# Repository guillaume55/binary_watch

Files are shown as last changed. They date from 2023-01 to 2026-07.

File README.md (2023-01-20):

# Binary watch

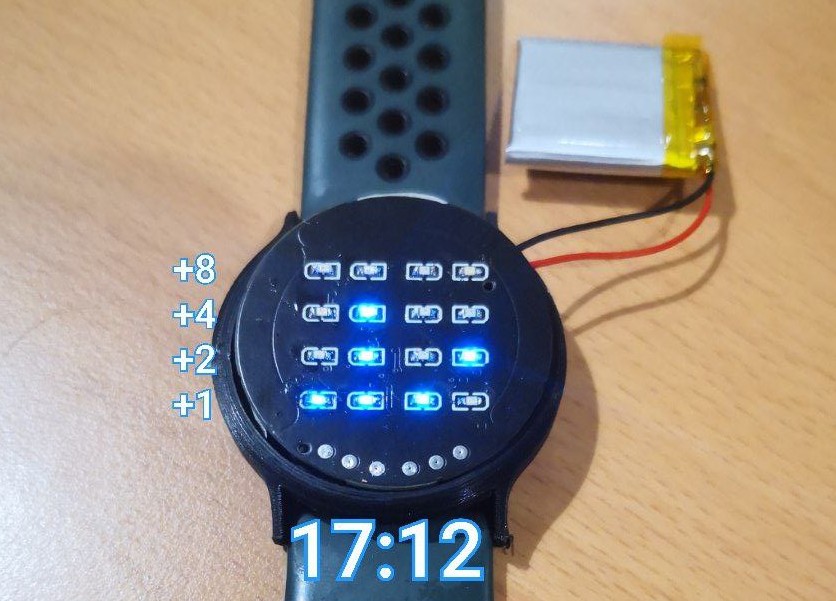
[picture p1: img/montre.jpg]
Binary watch


## How to read time
How to read it (BCD, binary coded digits)
Each digit is separated. The two first digits are for the hours, the two last for minutes
the Bottom digit adds 1, the second 2, the third 4, and the top one 8
For instance if # are on and _ are off

```
//First screen, time (24h format)
_ _ _ _
_ _ # #
_ # _ #
# # _ #

1 3:4 7

//second screen, date (DD/MM)
_ _ _ _
_ _ _ _
_ # _ #
# _ _ #

1 2:0 3 (March 12th)

//third screen, stop watch (indicated led will be on for one second (3rd led, 3rd screen) and the stopwatch will begin counting)
_ _ # _
_ _ _ _
_ _ _ _
_ _ _ _

1 3:4 7

//last screen, Full battery level here
_ _ _ #
_ _ _ #
_ _ _ #
_ _ _ #
```

## Features
* Read time and date (24h format, DD/MM)
* Set time and date
* Use stopwatch
* Battery level

## Four different screens
Navigate between screens with right button
Return to first screen with top button
* Display time (24h format)
* Display date (DD/MM)
* Stopwatch
* See battery level (will return to first screen after few seconds)

## How to use it

### Powered on, screen off (Idle)
Use top button to unlock (wake up from sleep) the watch. It will go to sleep after ON_DURATION (default 10s)
It can be a bit long for the watch to show something as the default pooling interval is 3s.

### Main screen with menus
* Right button: Set time (and date)
* Top button: Return to time display (menu index 0, useful if you are lost)
* Left button: Change mode, Time(1), Date(2), Stopwatch(3), Remaining battery(4) in this order. Lower led will be on for one second to indicate the index before displaying the mode

### Set time and date
An animation will tell you that you have clicked on setTime
* Right button: go to next digit to modify. Hours are modified at the same time, minutes are digit by digit)
* Top button: no action
* Left button: increase the time or date

A second animation (faster) will tell you that you now have to set the date (DD/MM). When done, press left. Last animation, and main screen will appear. Year should be written manually

### Stopwatch
* Right button: Next menu (will be battery level)
* Top button: No action
* Left button: Pause/Resume

### Battery level
Show battery level as a vertical bar on last column
```
//Full battery  --> low battery
_ _ _ #             _ _ _ _
_ _ _ #             _ _ _ _
_ _ _ #             _ _ _ _
_ _ _ #             _ _ _ #

```

## Power consumption
* 0.44mA in sleep (standby) mode. Wake up sometimes to poll user touch on button (Would need more tools to see average consumption)

## BOM
* SWD programmer (I use Seeedstudio XIAO as DAPLINK, see https://wiki.seeedstudio.com/Seeeduino-XIAO-DAPLink/)
* PCB, files in PCB/ are JLCPCB ready
* 3D printed or machined case
* 22mm watch strap
* At least 3 crocodile pliers
* 302323 battery (110mAh)
* Wireless charger

## Getting started with XIAO as DAPLINK and Arduino IDE
First, connect the programmer. For XIAO, connect
* XIAO GND to GND
* XIAO VCC to watch Vin on the microcontroller side
* XIAO 9 to Watch SWDIO
* XIAO 10 to Watch SWDCLK

Install libraries
* Adafruit freetouch (from arduino library manager)
* RTCZero (from arduino library manager)

Now burn bootloader and program it
* Start XIAO in bootloader mode (connect usb and restart it twice (see SeeedStudio page)
* Select Arduino Zero (programming port) board and XIAO port (Don't select XIAO BOARD!)
* Burn Bootloader
* Flash board (CRTL + U)

## Print case
Current version should be printed, next will be machinable
Use small layer heights

## PCB
You can provide directly file to JLCPCB
I have chosen one side assembly (microcontroler side) to reduce cost
I hand soldered leds, it can be cleaner but it's a fair job. You can train on another PCB because leds are very small. You should use a good quality precision iron, a standard size will make the job too hard and the looks terrible

## Known issue
After programming, the watch sleeps at 7.28mA. No idea why, but the problem disappear after restart

## Possible improvements
* Don't use arduino framework, there is room to improve consumption by reducing clock speed for example
* Use a more precise oscillator (as the precision is very low) or use the internal oscillator only
* Reset button or pad, maybe replace front 2.8V pad by reset pad
* Use another microcontroller optimized for low power, for example SAML21 (not in stock and available for assembly) or a STM32
* Improve hardware consumption

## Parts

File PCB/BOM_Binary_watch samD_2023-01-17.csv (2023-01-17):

ID | Name | Designator | Footprint | Quantity | Manufacturer Part | Manufacturer | Supplier | Supplier Part | Price
1 | 1uF | C1,C2,C24 | C0402 | 3 | CL05A105KA5NQNC | SAMSUNG | LCSC | C52923 | 0.001
2 | 10uF | C14,C21,C22 | C0402 | 3 | CL05A106MQ5NUNC | SAMSUNG | LCSC | C15525 | 0.001
3 | 100nF | C23,C28,C29 | C0402_NEW | 3 | CL05B104KO5NNNC | SAMSUNG(三星) | LCSC | C1525
4 | 10pF | C26,C27 | C0402 | 2 | CL05C100JB5NNNC | SAMSUNG(三星) | LCSC | C32949 | 0.001
5 | HDR-F-2.54_1x2 | H1,H2 | PADS_FOR_BATTERY | 2 |  |  | LCSC | C49661 | 0.006
6 | 19-217/GHC-YR1S2/3T | LED1EMERALD | LED0603-R-RD | 1 | 19-217/GHC-YR1S2/3T | EVERLIGHT(亿光) | LCSC | C72043 | 0.004
7 | 19-213/Y2C-CQ2R2L/3T(CY) | LED1YELLOW | LED0603-R-RD | 1 | 19-213/Y2C-CQ2R2L/3T(CY) | EVERLIGHT(亿光) | LCSC | C72038 | 0.004
8 | 19-217/BHC-ZL1M2RY/3T | LED2BLUE,LED3BLUE,LED4BLUE,LED5BLUE,LED6BLUE,LED7BLUE,LED8BLUE,LED9BLUE,LED10BLUE,LED11BLUE,LED12BLUE,LED13BLUE,LED14BLUE,LED15BLUE | LED0603-R-RD_BLUE | 14 | 19-217/BHC-ZL1M2RY/3T | EVERLIGHT(亿光) | LCSC | C72041 | 0.003
9 | CONN-TH_3P-P5.00 | P1 | QTOUCH-BUTTONS | 1 |  |  | LCSC
10 | 100K | R1,R2 | R0402 | 2 | 0402WGF1003TCE | UniOhm | LCSC | C25741
11 | 10K | R3,R4 | R0402 | 2 | 0402WGF1002TCE | UniOhm | LCSC | C25744
12 | 1K | RN1,RN2,RN4,RN5 | RES-ARRAY-SMD_0603-8P-L3.2-W1.6-BL | 4 | 4D03WGJ0102T5E | UniOhm | LCSC | C20197 | 0.001
13 | MCP73831T-2ACI/OT | U2 | SOT-23-5_L3.0-W1.7-P0.95-LS2.8-BR | 1 | MCP73831T-2ACI/OT | Microchip Tech | LCSC | C424093 | 0.128
14 | ATSAMD21G18A-AU | U3 | TQFP-48_L7.0-W7.0-P0.50-LS9.0-BL | 1 | ATSAMD21G18A-AU | MICROCHIP(美国微芯) | LCSC | C78624 | 0.722
15 | AMS1117-5.0_C2718490 | U5 | SOT-89-3_L4.5-W2.5-P1.50-LS4.2-BR | 1 | AMS1117-5.0 | JSMSEMI(杰盛微) | LCSC | C2718490 | 0.017
16 | MD57E28QC3 | U6 | SOT-23-5_L2.9-W1.6-P0.95-LS2.8-BL | 1 | MD57E28QC3 | 明达微 | LCSC | C920560 | 0.021
17 | pad | U8,U11,U12,U14,U15,U16 | PAD | 6
18 | 32.768kHz | X3 | OSC-SMD_L3.2-W1.5 | 1 | Q13FC1350000300 | EPSON(爱普生) | LCSC | C99010 | 0.043

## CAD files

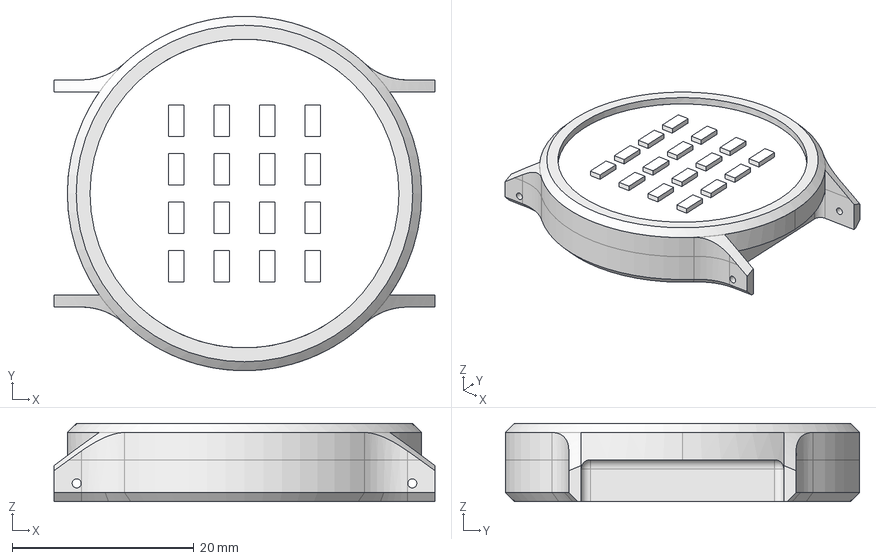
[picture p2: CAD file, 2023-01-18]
CAD/montre.FCStd
41.9 x 39.0 x 8.60 mm
PCB
battery
wireless receiver
watch 3
led

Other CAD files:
CAD/montre.stl

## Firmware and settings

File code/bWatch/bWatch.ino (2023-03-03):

/*******************************
 * Binary watch version 0.1
 *
 * How to read it (BCD, binary coded digits)
 * Each digit is separated. The two first digits are for the hours, the two last for minutes
 * the Bottom digit adds 1, the second 2, the third 4, and the top one 8
 * For instance if # are on and _ are off
 *      _ _ _ _           ex 2)   _ _ _ _
 *      _ _ # #                   _ _ _ #
 *      _ # _ #                   # _ # _
 *      # # _ #                   _ # # #
 *      1 3:4 7                   2 1:3 5
 *
 * Buttons
 * Top button, Unlock and show time
 * Left button : set time and then date
 * Right button : change mode (time, date, stopwatch, remaining battery)
 * See readme for more details
 * Power consumption depend a lot on selected board. Arduino zero consumes 0.44mA during standby, sparkfun SAMD21 Dev only 0.27mA
 *
 *******************************/

 //Arduino_MCHPTouch.h ?

#include <RTCZero.h>
#include <time.h>
#include "Adafruit_FreeTouch.h"
#include "ArduinoLowPower.h"

#define BUTTON_RIGHT 42//PA03
#define BUTTON_LEFT A5//PB02
#define BUTTON_TOP A1//PB08
#define BATTERY_PROBE 25 //PB03;

#define QTOUCH_THRESHOLD 500

#define ON_DURATION 10000 //sec during which the watch is showing time
#define SLEEP_DURATION 3 //sec during which the device is sleeping. Correspond to the max amount of time between 2 readings of the capacitive button

Adafruit_FreeTouch qt_top = Adafruit_FreeTouch(BUTTON_TOP, OVERSAMPLE_4, RESISTOR_50K, FREQ_MODE_NONE);
Adafruit_FreeTouch qt_left = Adafruit_FreeTouch(BUTTON_LEFT, OVERSAMPLE_4, RESISTOR_50K, FREQ_MODE_NONE);
Adafruit_FreeTouch qt_right = Adafruit_FreeTouch(BUTTON_RIGHT, OVERSAMPLE_4, RESISTOR_50K, FREQ_MODE_NONE);

RTCZero rtc;

//Pins for Arduino Zero (Programming port) board. Do not forget to burn the bootloader
const int ledPin [4][4] = { {0,0,17,16}, //1st digit of hours, The two first leds are not connected to the uC
                          {9,8,18,14}, //2nd digit of hours
                          {24,23,7,6}, //1st digit of min
                          {22,38,20,21}  //2nd digit of min
                        };

int ledState [4][4] = { {0,0,0,0}, //1st digit of hours
                        {0,0,0,0}, //2nd digit of hours
                        {0,0,0,0}, //1st digit of min
                        {0,0,0,1}  //2nd digit of min, shows one led to say that everything is working
                      };

unsigned long pm = 0;
uint8_t menuIndex = 0; //(dispaly time, date, stopwatch, remaining battery)
bool wasSleeping = false;

void setup() {
  //set leds as ouputs
  for(int i=0; i<4; i++)
  {
    for(int j=0; j<4; j++)
    {
      pinMode(ledPin[i][j], OUTPUT);
      digitalWrite(ledPin[i][j], ledState[i][j]);
    }
  }

  ledsTest(3); // set a delay to ease programming, sleep mode can interfere with prog mode
  //not actually needed if we use a programmer

  // Setup the RTC
  rtc.begin(false); //don't reset time

  //disable usb 
  USBDevice.detach();

//most of the power consumption is here. make the standby current goes from 0.08mA to 0.27mA
  if (! qt_top.begin() || ! qt_left.begin() || ! qt_right.begin() )  //eror with qtouch makes col 2 blink
  {
    digitalWrite(21,!digitalRead(21));
    delay(500);
  }
  saveTime(12, 11); //the watch is not supposed to shudown. Display at least something when it boots
}

void loop() {

  if(qt_top.measure() > QTOUCH_THRESHOLD)  //unlock and display the time
  {
    wasSleeping = false;
    timeToLeds();
    delay(3000);
    pm = millis();
    menuIndex = 0; //return to first screen (time) if you are lost
  }

  if(qt_right.measure() > QTOUCH_THRESHOLD /*&& wasSleeping = false*/)
  {
    wasSleeping = false;
    menuIndex = (menuIndex+1) % 4;
    //show index for 1s
    digitalWrite(ledPin[menuIndex][0], HIGH);
    delay(500);
    digitalWrite(ledPin[menuIndex][0], LOW);

    if(menuIndex == 0)
      timeToLeds();
    if(menuIndex == 1)
      dateToLeds();
    if(menuIndex == 2){
      stopwatch();
      menuIndex++; //don't forget to inc menu because stopwatch is a new screen
    }
    if(menuIndex == 3){
      remainingBattery(3000);
    }
    pm = millis();
  }

  if(qt_left.measure() > QTOUCH_THRESHOLD /*&& wasSleeping = false*/)
  {
    wasSleeping = false;
    ledsTest(0.75);
    setTime();
    ledsTest(0.5); //faster animation
    setDate();
    ledsTest(0.5);

    menuIndex = 0; //return to time display
    pm = millis();
  }

  //sleeps after timeout or if we woke up and the user didn't touch any button
  if(millis() - pm > ON_DURATION || wasSleeping == true){
    // Sleep until the next interrupt
    ledsOff();
    wasSleeping = true;
    LowPower.sleep(3000);
  }
  delay(100);
}

//show the leds that are supposed to be on
void ledsShow()
{
  ledsOff();
  for(int i=0; i<4; i++)
  {
    for(int j=0; j<4; j++)
    {
      digitalWrite(ledPin[i][j], ledState[i][j]);
    }
  }
}

//shut off all leds
void ledsOff()
{
  for(int i=0; i<4; i++)
  {
    for(int j=0; j<4; j++)
    {
      digitalWrite(ledPin[i][j], 0);
    }
  }
}

void ledsColOff(int col)
{
    for(int j=0; j<4; j++)
    {
      digitalWrite(ledPin[col][j], 0);
    }
}

void ledsTest(float speed)
{
  for(int i=0; i<4; i++)
  {
    for(int j=0; j<4; j++)
    {
      digitalWrite(ledPin[i][j], 1);
      delay(100*speed);
      digitalWrite(ledPin[i][j], 0);
      delay(50*speed);
    }
  }
}

void remainingBattery(int time)
{
  ledsOff();
  int voltage = analogRead(BATTERY_PROBE);
  //voltage dividor cuts volts of the battery in half
  //Supply voltage is 2.8V

  //voltage = ( 2.8 * 1023 ) / voltage;
  if(voltage > 2200)
    digitToLedColumn(0b1111, 3);
  else if(voltage > 1600)
    digitToLedColumn(0b0111, 3);
  else if(voltage > 1100)
    digitToLedColumn(0b0011, 3);
  else {
    digitToLedColumn(0b0001, 3);
  }
  ledsShow();
  delay(time);  //stay a bit on this screen
  digitToLedColumn(0b0000,4); //remove on "buffer"
  ledsOff(); //shutdown leds
}

void timeToLeds()
{
  ledsOff();
  // Get time as an epoch value and convert to tm struct
  time_t epoch = rtc.getEpoch(); //we can use directly getHours and getMinutes but I'm coming from RtcCounter lib
  struct tm* t = gmtime(&epoch);

  int timeArr[4] = { ( (t->tm_hour/10) % 10 ),  //1st digit of hours
                     ( (t->tm_hour) % 10 ),  //2nd of hours
                     ( (t->tm_min/10) % 10 ),  //1st digit of min
                     ( (t->tm_min) % 10 )   //2nd of min
                    };

  for(int i=0; i<4; i++)  //read and copy the bits from digit to led digit
  {
    digitToLedColumn(timeArr[i],i);
  }
  ledsShow();
}

void dateToLeds() //close to TimeToLeds
{
  ledsOff();
  // Get time as an epoch value and convert to tm struct
  //time_t epoch = rtcCounter.getEpoch();
  time_t epoch = rtc.getEpoch();
  struct tm* t = gmtime(&epoch);

  //do +1 because RTC starts at 0 and human month and days at 1
  int timeArr[4] = {(t->tm_mday+1) / 10,  //1st digit of month day
                    (t->tm_mday+1) % 10,  //2nd of month day
                    (t->tm_mon + 1) / 10,  //1st digit of month
                    (t->tm_mon + 1) % 10  //2nd of month
                  };

  for(int i=0; i<4; i++)  //read and copy the bits from digit to led digit
  {
    digitToLedColumn(timeArr[i], i);
  }
  ledsShow();
}

void digitToLedColumn(uint8_t digit, int column)
{
  for(int i=0; i<4; i++)  //read and copy the bits from digit to led digit
  {
    ledState[column][3-i] = bitRead(digit, i); //starting from the rightmost bit and copying it to the bottom led
  }
}

void setTime()
{
  int index = 0;
  uint8_t hour = rtc.getHours();
  uint8_t minute = 11; //the two bottom leds will be on

  //display current value
  hour = hour-1; //if init will do +1, counter it
  bool doInit = 1; //force display

  //top button to quit if not finished, better to click right
  while(qt_top.measure() < QTOUCH_THRESHOLD+100 && index < 4)
  {
    //hours modified, edit sec
    if(qt_right.measure() > QTOUCH_THRESHOLD){
      if(index == 0){
        index += 2; //hours in one shot
      }
      else
        index++; //set minutes in two steps

      ledsShow();
      delay(300);
      ledsOff();
    }

    if( (qt_left.measure() > QTOUCH_THRESHOLD || doInit == 1) && index < 4){
      doInit = 0; //do it once only

      if(index == 0) //1st of hour
        hour = (hour + 1) % 24;
      if(index == 2) //1st of min
        minute = (minute + 10) % 60;
      if(index == 3){
        if(minute % 10 == 9)
          minute -= 10; //don't modify the tens digit of the minute, too strange and unexpected when we set the time
        minute = (minute + 1) % 60;

      }

      //refresh leds
      uint8_t timeArr[4] = {hour / 10,  //1st digit of min
                         hour % 10,  //2nd of hours
                         minute / 10,  //1st digit of min
                         minute % 10   //2nd of min
                    };

      for(int i=0; i<4; i++)  //read and copy the bits from digit to led digit
      {
        digitToLedColumn(timeArr[i], i);
      }
      ledsShow();
      delay(300);

    }

    //blink active column(s)
    ledsColOff(index); //okay since it does not modify leds array
    if(index == 0)  //if hours, blink 2 col
      ledsColOff(index+1);
    delay(50);
    ledsShow();
    delay(200);

  }
  saveTime(hour, minute);
}

void saveTime(uint8_t hour, uint8_t minute)
{
  rtc.setHours(hour);
  rtc.setMinutes(minute);
}

void setDate()
{
  int index = 0;
  uint8_t month = 0;
  uint8_t mday = 0; // month day (not week day)

  //display current value
  bool doInit = 1;

  while(qt_top.measure() < QTOUCH_THRESHOLD+100 && index < 4)
  {
    if(qt_right.measure() > QTOUCH_THRESHOLD){
      index += 2;
      ledsShow();
      delay(300);
      ledsOff();
    }

    if((qt_left.measure() > QTOUCH_THRESHOLD || doInit == 1) && index < 4){
      doInit = 0; //do it once only

      if(index == 0) //first we modify mday
        mday = (mday + 1) % 31;
      if(index == 2) //then month
        month = (month + 1) % 12;

      //refresh leds
      uint8_t timeArr[4] = {(mday+1) / 10, //do +1 because January 1st is month 0 and mday 0 for ex, starts at 0 not 1
                         (mday+1) % 10,
                         (month+1) / 10,
                         (month+1) % 10
                    };

      for(int i=0; i<4; i++)  //read and copy the bits from digit to led digit
      {
        digitToLedColumn(timeArr[i], i);
      }
      ledsShow();
      delay(300);
    }

    if(index < 4) { // don't forget the if ! Will try to access index over array length else
      //blink active column(s)
      ledsColOff(index); //okay since it does not modify leds array
      ledsColOff(index+1);//blink two colums
      delay(50);
      ledsShow();
      delay(200);
    }
  }
  saveDate(mday, month);
  
}

void saveDate(uint8_t day, uint8_t month)
{
  rtc.setDay(day);
  rtc.setMonth(month);
}

void stopwatch()
{
  //first column is now min and last is last digit of seconds
  unsigned long sTime = millis();
  unsigned long oneHertz = millis();

  bool paused = false; //don't start in pause mode as it's difficult to understand what's happening if it do nothing

  ledsOff();

  while(qt_right.measure() < QTOUCH_THRESHOLD)
  {

    //left button will pause
    if(qt_left.measure() > QTOUCH_THRESHOLD)
    {
      paused = !paused;
      ledsOff();
      delay(500);
      ledsShow();
      delay(500);
    }

    if(millis()-oneHertz >= 1000)
    {
      oneHertz = millis();

      if(paused) //pause correspond to delaying startTime
        sTime += 1000;

      //display time from start
      uint8_t minutes = ( (millis() - sTime) / 1000) / 60;
      uint8_t sec = ( ((millis() - sTime) / 1000) % 60);

      uint8_t timeArr[4] = {minutes / 10 ,  //1st digit of min
                         minutes % 10,  //2nd of min
                         sec / 10,  //1st digit of sec
                         sec % 10   //2nd of sec
                    };

      for(int i=0; i<4; i++)  //read and copy the bits from digit to led digit
      {
        digitToLedColumn(timeArr[i], i);
      }
      ledsShow();
    }
  }
}

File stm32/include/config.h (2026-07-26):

#ifndef CONFIG_H
#define CONFIG_H

/* ── Timing ─────────────────────────────────────────────────────────── */
#define TIME_ON_MS          10000U  /* display duration after short press    */
#define STARTUP_LED_ON_MS   500U    /* startup anim: ms per LED turn-on      */
#define STARTUP_LED_OFF_MS  200U    /* startup anim: ms per LED turn-off     */
#define BLINK_PERIOD_MS     125U    /* 4 Hz half-period (125 ms on/off)      */
#define SHORT_PRESS_MAX_MS  800U    /* < this → short press                  */
#define LONG_PRESS_MIN_MS   2000U   /* > this → long press                   */
#define DEBOUNCE_MS         100U    /* button debounce window                */
#define BATTERY_DISP_MS     5000U   /* battery display duration              */
#define SET_TIMEOUT_MS      10000U  /* time-set: no-input cancel timeout     */
#define ADC_SAMPLES         8U      /* ADC samples averaged for VDD measure  */

/* ── GPIO ───────────────────────────────────────────────────────────── */
#define LED_GPIO_PORT   GPIOA
#define SW_GPIO_PORT    GPIOA
#define SW1_PIN         GPIO_PIN_5   /* active LOW, EXTI5 */
#define SW2_PIN         GPIO_PIN_6   /* active LOW, EXTI6 */

/* ── Charlieplexing ─────────────────────────────────────────────────── */
#define NUM_LEDS        16U          /* L1–L16 on PA0–PA4 (5×4=20 max)       */
#define L3_IDX          2U           /* L3 spare — defined but never driven   */
#define L4_IDX          3U           /* L4 battery indicator — set_battery_led() only */

/* ── Charlieplex scan timer ─────────────────────────────────────────── */
/* TIM2: 16 MHz / (PSC+1) / (ARR+1) = 1 kHz  →  PSC=15, ARR=999       */
#define CHARLIE_TIM_PSC 15U
#define CHARLIE_TIM_ARR 999U

#endif /* CONFIG_H */

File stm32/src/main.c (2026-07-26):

#include "stm32l0xx_hal.h"
#include "config.h"
#include "charlieplex.h"
#include "rtc.h"
#include "buttons.h"
#include "battery.h"
#include "display.h"
#include "power.h"

/* ── State machine ──────────────────────────────────────────────────── */

typedef enum {
    STATE_STARTUP_ANIM,
    STATE_SHOW_TIME,
    STATE_SET_TIME,
    STATE_SHOW_BATTERY,
    STATE_SLEEP,
} app_state_t;

static app_state_t state = STATE_STARTUP_ANIM;

/* ── Time-setting context ───────────────────────────────────────────── */

static struct {
    uint8_t      digit;         /* 0=H_tens 1=H_units 2=M_tens 3=M_units */
    uint8_t      vals[4];       /* working copy of each BCD digit         */
    watch_time_t saved;         /* snapshot to restore on cancel          */
    uint32_t     last_action;   /* HAL_GetTick() of last SW event         */
} set_ctx;

/* ── Helpers ────────────────────────────────────────────────────────── */

static void refresh_time_display(void)
{
    watch_time_t t;
    rtc_get_time(&t);
    set_leds(time_to_led_mask(&t));
}

/* ── Startup animation ──────────────────────────────────────────────── */

static void run_startup_anim(void)
{
    uint16_t mask = 0U;

    /* Sweep ON: LED1 → LED14, each step adds one LED */
    for (int i = 0; i < (int)NUM_LEDS; i++) {
        mask |= (uint16_t)(1U << i);
        set_leds(mask);
        HAL_Delay(STARTUP_LED_ON_MS);
    }

    /* Sweep OFF: LED14 → LED1, each step removes one LED */
    for (int i = (int)NUM_LEDS - 1; i >= 0; i--) {
        mask &= (uint16_t)~(1U << i);
        set_leds(mask);
        HAL_Delay(STARTUP_LED_OFF_MS);
    }
}

/* ── Time-setting helpers ───────────────────────────────────────────── */

static void set_mode_enter(void)
{
    rtc_get_time(&set_ctx.saved);
    set_ctx.digit       = 0;
    set_ctx.vals[0]     = set_ctx.saved.hours   / 10U;
    set_ctx.vals[1]     = set_ctx.saved.hours   % 10U;
    set_ctx.vals[2]     = set_ctx.saved.minutes / 10U;
    set_ctx.vals[3]     = set_ctx.saved.minutes % 10U;
    set_ctx.last_action = HAL_GetTick();
}

static void set_mode_update_leds(uint8_t blink_on)
{
    uint16_t mask = 0U;
    for (uint8_t d = 0U; d < 4U; d++) {
        /* Suppress the blinking digit when blink phase is off */
        if (d == set_ctx.digit && !blink_on) continue;
        mask |= digit_mask(d, set_ctx.vals[d]);
    }
    set_leds(mask);
}

/* Increment the active digit with BCD validity and wrap */
static void set_mode_increment(void)
{
    uint8_t d = set_ctx.digit;
    set_ctx.vals[d]++;

    uint8_t limit;
    if (d == 0U) {
        limit = 2U;  /* H_tens: 0–2 */
    } else if (d == 1U) {
        limit = (set_ctx.vals[0] == 2U) ? 3U : 9U; /* H_units: 0–3 when H_tens=2 */
    } else if (d == 2U) {
        limit = 5U;  /* M_tens: 0–5 */
    } else {
        limit = 9U;  /* M_units: 0–9 */
    }

    if (set_ctx.vals[d] > limit) set_ctx.vals[d] = 0U;
    set_ctx.last_action = HAL_GetTick();
}

/* Validate current digit and advance; save to RTC on last digit */
static void set_mode_validate(void)
{
    set_ctx.digit++;
    set_ctx.last_action = HAL_GetTick();

    if (set_ctx.digit >= 4U) {
        watch_time_t t;
        t.hours   = set_ctx.vals[0] * 10U + set_ctx.vals[1];
        t.minutes = set_ctx.vals[2] * 10U + set_ctx.vals[3];
        rtc_set_time(&t);
    }
}

/* ── Main ───────────────────────────────────────────────────────────── */

int main(void)
{
    HAL_Init();
    power_init();          /* enable PWR, backup domain access       */
    SystemClock_Config();  /* HSI16 as SYSCLK, start LSE             */

    charlie_init();        /* configure PA0-PA4 and TIM2             */
    buttons_init();        /* configure PA5-PA6 and EXTI4_15         */
    rtc_init();            /* init RTC on LSE, cold-start = 00:00    */

    charlie_start();

#ifdef BOARD_TEST
    /* Visual LED validation: light L1–L16 one by one, 300 ms each.
       Enable by adding -DBOARD_TEST to build_flags in platformio.ini.  */
    charlie_test_all_leds(300U);
#endif

    run_startup_anim();

    refresh_time_display();
    state = STATE_SHOW_TIME;
    uint32_t display_deadline = HAL_GetTick() + TIME_ON_MS;

    /* Time-set blink state */
    uint8_t  blink_on      = 1U;
    uint32_t blink_tick    = HAL_GetTick();

    /* Battery display */
    uint8_t  batt_pct      = 0U;
    uint32_t batt_deadline = 0U;

    while (1) {
        btn_event_t ev = buttons_poll();

        switch (state) {

        /* ── Sleep ──────────────────────────────────────────────── */
        case STATE_SLEEP:
            set_leds(0U);
            set_battery_led(0U);
            charlie_stop();
            buttons_clear_pending();
            enter_stop();          /* blocks until EXTI wakeup      */
            charlie_start();
            refresh_time_display();
            state            = STATE_SHOW_TIME;
            display_deadline = HAL_GetTick() + TIME_ON_MS;
            break;

        /* ── Normal time display ─────────────────────────────────── */
        case STATE_SHOW_TIME:
            if (ev == BTN_SW1_LONG) {
                set_mode_enter();
                blink_on   = 1U;
                blink_tick = HAL_GetTick();
                state      = STATE_SET_TIME;
                set_mode_update_leds(blink_on);

            } else if (ev == BTN_SW2_LONG) {
                batt_pct      = battery_measure_percent();
                batt_deadline = HAL_GetTick() + BATTERY_DISP_MS;
                set_leds(0U);             /* blank BCD display          */
                set_battery_led(1U);      /* light L4 (battery LED)     */
                state = STATE_SHOW_BATTERY;

            } else if (ev == BTN_SW1_SHORT || ev == BTN_SW2_SHORT) {
                display_deadline = HAL_GetTick() + TIME_ON_MS;
                refresh_time_display();

            } else if (HAL_GetTick() >= display_deadline) {
                state = STATE_SLEEP;
            }
            break;

        /* ── Time setting ────────────────────────────────────────── */
        case STATE_SET_TIME:
            /* 4 Hz blink: toggle every BLINK_PERIOD_MS */
            if (HAL_GetTick() - blink_tick >= BLINK_PERIOD_MS) {
                blink_on   = !blink_on;
                blink_tick = HAL_GetTick();
                set_mode_update_leds(blink_on);
            }

            if (ev == BTN_SW1_SHORT) {
                set_mode_increment();
                blink_on   = 1U;
                blink_tick = HAL_GetTick();
                set_mode_update_leds(blink_on);
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

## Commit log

2023-01-18 with rtcCounter lib
    [montre.FCStd, montre.stl]
2023-01-20 doesn't need volatile anymore
    [bWatch.ino]
2026-06-04 Add STM32L031D6P PlatformIO project with full charlieplexing firmware
    14 blue LEDs on PA0-PA4 (charlieplex), TIM2 1 kHz scan, RTC on LSE,
    Stop-mode idle with EXTI5/6 wakeup, battery measurement via VREFINT,
    BCD time display and time-setting state machine.
    https://claude.ai/code/session_01WgjdJ1qohaZV74CJ2ntiFC
2026-06-14 Fix MCU target: STM32L031D6P does not exist, use STM32L031F6P6 (TSSOP20)
    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
2026-07-26 Remap charlieplex table to match re-routed PCB (L1–L16)
    - Replace led_table with 16-entry table verified from schematic connectivity
    - L3 (PA1→PA2) kept in table but never driven (spare reserved)
    - L4 (PA3→PA2) isolated as battery indicator; driven exclusively via
    set_battery_led(), never via BCD display path
    - time_to_led_mask/digit_mask updated for new bit positions:
    H_tens bits 0-1 (L1-L2), H_units bits 4-7 (L5-L8),
    M_tens bits 8-11 (L9-L12), M_units bits 12-15 (L13-L16)
    - split active_mask into bcd_mask + bat_on; rebuild_mask() merges them
    - add charlie_test_all_leds(): lights L1→L16 sequentially (BOARD_TEST flag)
    - main.c STATE_SHOW_BATTERY uses set_battery_led() for L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
    [charlieplex.c, config.h, main.c]
